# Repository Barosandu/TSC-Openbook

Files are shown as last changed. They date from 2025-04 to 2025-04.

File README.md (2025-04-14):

# Proiect Ariton Alexandru -- TSC -- Openbook

### Pasii de implementare
* Am creat schematicul 2D.
* Am creat PCB-ul, am intampinat niste erori:
    * **Via(hole) error** la componenta USB: am modificat footprint-ul componentei.
    * **Wire to wire error**: am rutat firele manual
* Am atribuit fiecarei componente din library cate un model 3D, si am creat placa 3d (*Push to 3D*)
* Am creat modelele pentru Display si Baterie dupa specificatiile din datasheeturi

### Diagrama block
* salvata in folder cu numele BlockSchematic.png
* Pini ESP32-C6
    * Interfetele SPI -- folosite pentru conectarea la Display
    * Este conectat la senzorul BME688 prin I2C.
    * E conectat la portul USB-C prin interfata USB
    * E conectat la butoane prin porturile GPIO

## Configurație pini ESP32-C6

| Componentă | Pin ESP32-C6 |
|---|---|
| Display SPI | MOSI, CLK, CS, DC |
| BME688 | SDA, SCL (I2C) |
| Butoane | GPIO1, GPIO2, GPIO3 |
| USB-C | D+, D−, VBUS |

Diagrama Bloc

### Componente Folosite

MCU: ESP32-C6-WROOM-1 (sau echivalent), datorita integrarii Wi-Fi 6, BLE 5 si a puterii de procesare ridicate.

Afisaj: Waveshare WSH-13187, e-Paper de 7.5 inch (sau echivalent), cu rezolutie 800x480.

Senzori: Bosch BME688 – pentru temperatura, umiditate, presiune si calitatea aerului.

Baterie: Baterie Li-Polimer de 2500mAh, cu circuit de protectie integrat.

Indicator nivel baterie (Fuel Gauge): Maxim MAX17048 sau echivalent.

Circuit de incarcare: Microchip MCP73831 sau echivalent.

Butoane: Comutatoare tactile Panasonic EVQ-Q2A03W (sau echivalent).

Conector USB-C: Amphenol 12401641E4R (sau echivalent).

Conector pentru card microSD: Attend Tech 112A-TAAR-R03 (sau echivalent).

Ceas in timp real (RTC): DS3231 (sau echivalent), cu supercapacitor pentru backup.

Conector Qwiic/Stemma: pentru conectarea rapida a senzorilor compatibili.

| Componenta | Link |
|---|---|
| adafruit_led | [Link](https://www.snapeda.com/parts/KP-1608SURCK/Kingbright/view-part/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) |
| Button_customv1 | [Link](https://industry.panasonic.com/global/en/products/control/switch/light-touch/number/evqpuj02k) |
| Eagle_ltspice_c | [Link](https://componentsearchengine.com/part-view/0402WGF3001TCE/UNI-ROYAL(Uniroyal%20Elec)) |
| ESP32_WROVER_AVX—SD0805S020S1R0 | [Link](https://ro.mouser.com/ProductDetail/KYOCERA-AVX/SD0805S020S1R0?qs=jCA%252BPfw4LHbpkAoSnwrdjw%3D%3D) |
| ESP32_WROVER_BME680_BME680 | [Link](https://www.snapeda.com/parts/BME680/Bosch/view-part/?welcome=home) |
| ESP32_WROVER_EAGLE-LTSPICE_R | [Link](https://componentsearchengine.com/part-view/R0402%201%25%20100%20K%20(RC0402FR-07100KL)/YAGEO) |
| RCL_CPOL-EU | [Link](https://www.snapeda.com/parts/TAJB475K025RNJ/AVX/view-part/?t=capacitor%203528&con_ref=None) |
| SJ | [Link](https://grabcad.com/library/solder-jumpers-1) |
| R-URI | [Link](https://componentsearchengine.com/part-view/R0402%201%25%20100%20K%20(RC0402FR-07100KL)/YAGEO) |
| ESP32_WROVER_SPARKFUN-DISCRETESEMI_MOSFET_PCH | [Link](https://componentsearchengine.com/part-view/DMG2305UX-7/Diodes%20Incorporated) |
| ESP32_WROVER_SPARKFUN-IC-POWER_MCP73831 | [Link](https://eu.mouser.com/ProductDetail/Microchip-Technology/MCP73831T-2ACI-OT?qs=yUQqVecv4qvbBQBGbHx0Mw%3D%3D) |
| TP | Facut Manual |
| FH34SRJ-24S-0.5SH_99_ | [Link](https://componentsearchengine.com/part-view/FH34SRJ-24S-0.5SH(99)/Hirose) |
| MAX17048G+T10 | [Link](https://www.snapeda.com/parts/MAX17048G+T10/Analog+Devices/view-part/) |
| SAMACSYS_PARTS_USB4110-GF-A | [Link](https://componentsearchengine.com/part-view/USB4110-GF-A/GCT%20(GLOBAL%20CONNECTOR%20TECHNOLOGY)) |
| QWIIC_CONNECTOR | [Link](https://www.snapeda.com/parts/PRT-14417/SparkFun%20Electronics/view-part/?t=QWIIC_CONNECTORJS-1MM) |
| 112A-TAAR-R03_ATTEND | [Link](https://componentsearchengine.com/part-view/112A-TAAR-R03%20ATTEND/ATTEND) |
| 744043680IND_4828-WE-TPC_WRE | [Link](https://componentsearchengine.com/part-view/744043680/W%C3%BCrth%20Elektronik) |
| BD5229G-TR | [Link](https://componentsearchengine.com/part-view/BD5229G-TR/ROHM%20Semiconductor) |
| CPH3225A | [Link](https://componentsearchengine.com/part-view/CPH3225A/Seiko%20Semiconductors) |
| DS3231SN# | [Link](https://componentsearchengine.com/part-view/DS3231SN%23/Analog%20Devices) |
| ESP32-C6-WROOM-1-N8 | [Link](https://componentsearchengine.com/part-view/ESP32-C6-WROOM-1-N8/Espressif%20Systems) |
| MBR0530 | [Link](https://componentsearchengine.com/part-view/MBR0530/onsemi) |
| SI1308EDL-T1-GE3 | [Link](https://componentsearchengine.com/part-view/SI1308EDL-T1-GE3/Vishay) |
| USBLC6-2SC6Y | [Link](https://componentsearchengine.com/part-view/USBLC6-2SC6Y/STMicroelectronics) |
| W25Q512JVEIQ | [Link](https://componentsearchengine.com/part-view/W25Q512JVEIQ/Winbond) |
| XC6220A331MR-G | [Link](https://componentsearchengine.com/part-view/XC6220A331MR-G/Torex) |

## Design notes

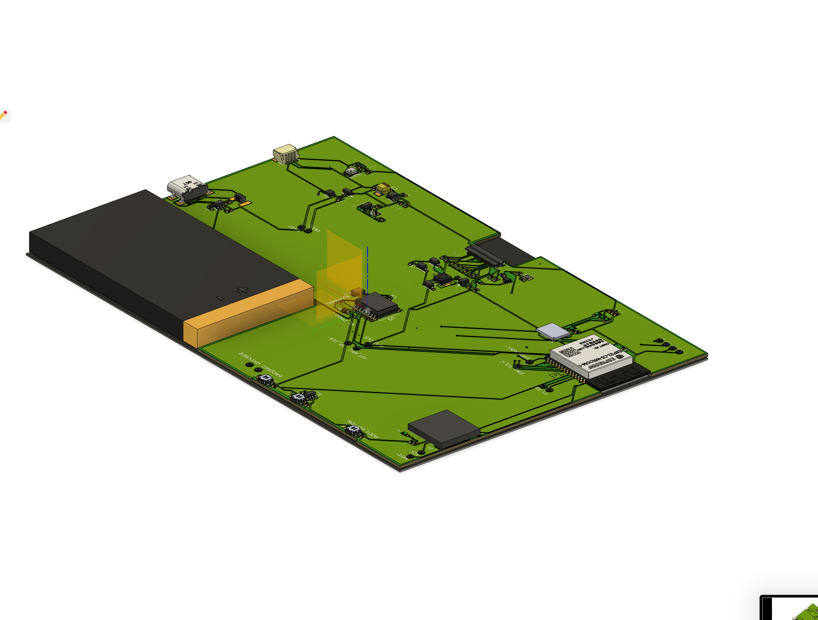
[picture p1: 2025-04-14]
Images/Screenshot 2025-04-14 at 20.04.46.png

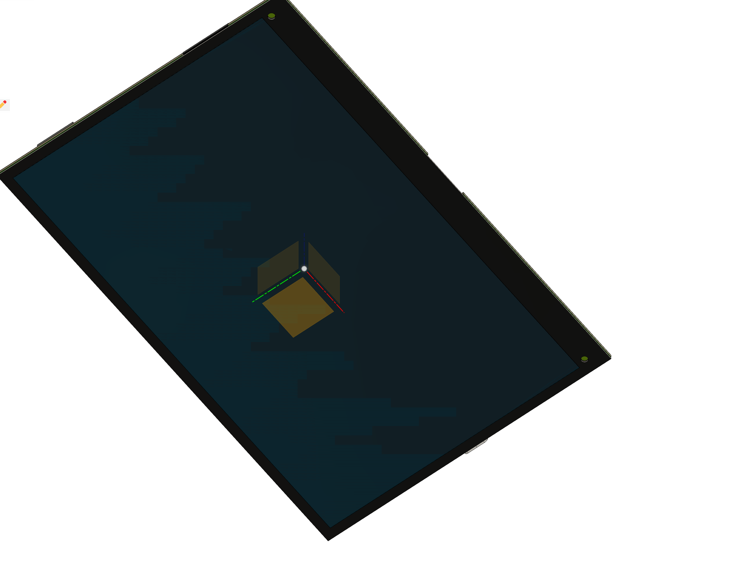
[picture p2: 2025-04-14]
Images/Screenshot 2025-04-14 at 20.04.55.png

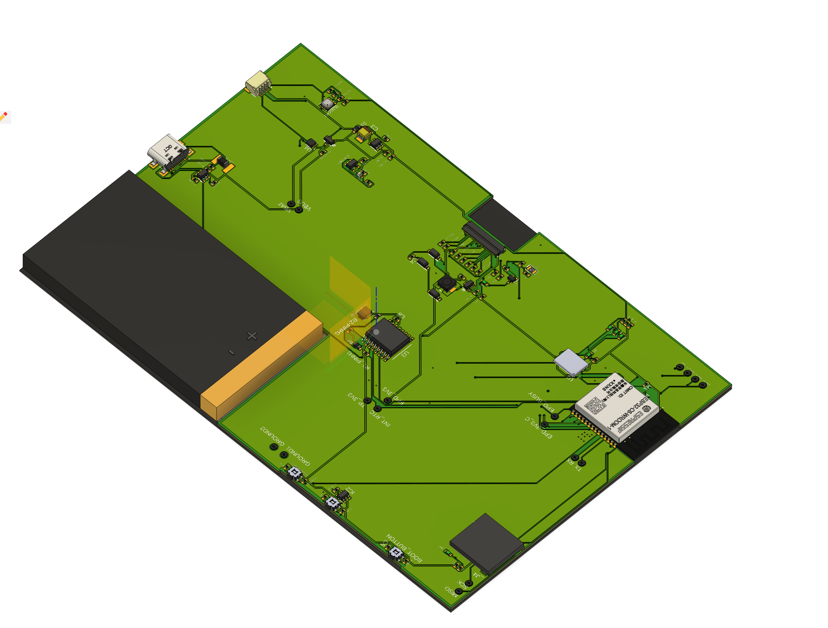
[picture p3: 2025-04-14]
Images/Screenshot 2025-04-14 at 20.04.41.png

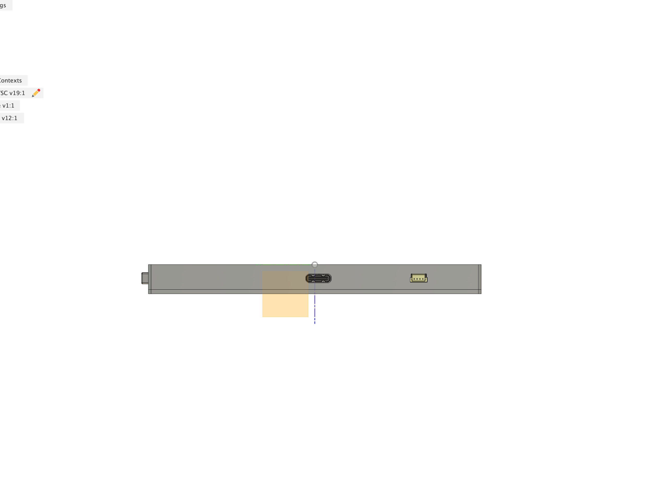
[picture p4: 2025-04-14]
Images/Screenshot 2025-04-14 at 20.05.17.png

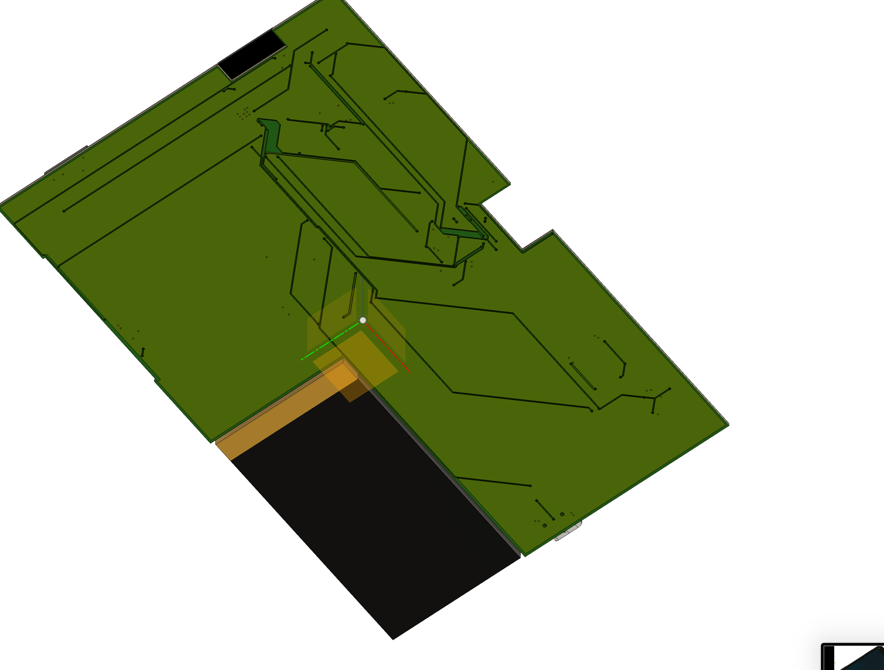
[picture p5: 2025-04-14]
Images/Screenshot 2025-04-14 at 20.05.00.png

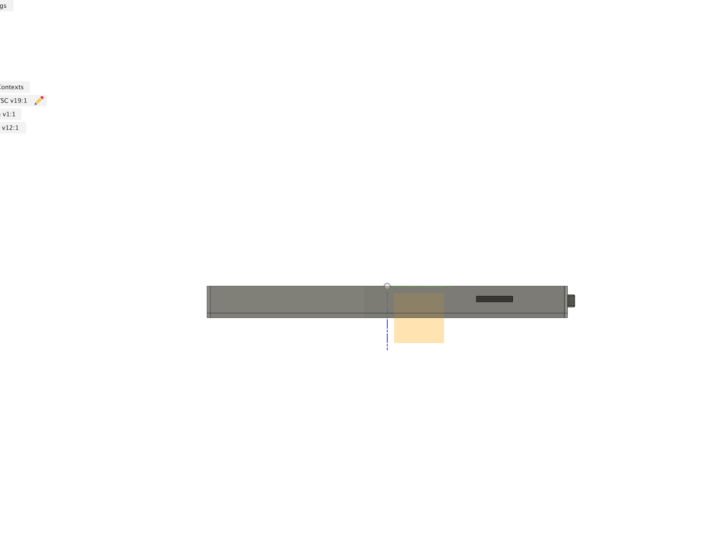
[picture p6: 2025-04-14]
Images/Screenshot 2025-04-14 at 20.05.25.png

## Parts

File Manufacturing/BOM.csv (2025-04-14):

Qty | Value | Device | Package | Parts | Description | ARROW_PART_NUMBER | ARROW_PRICE-STOCK | AVAILABILITY | CENTROID_NOT_SPECIFIED | CHECK_PRICES | COPYRIGHT | DATASHEET | DESCRIPTION | DIGIKEY_DESCRIPTION | DIGIKEY_PART_NUMBER | HEIGHT | LEAD_FREE | MANUFACTURER_NAME | MANUFACTURER_PART_NUMBER | MF | MFR_NAME | MOUSER_PART_NUMBER | MOUSER_PRICE-STOCK | MOUSER_TESTING_PART_NUMBER | MOUSER_TESTING_PRICE-STOCK | MP | MPN | PACKAGE | POPULARITY | PREFIX | PRICE | PROD_ID | PURCHASE-URL | ROHS | SNAPEDA_LINK | SPICEMODEL | SPICEPREFIX | TEMPERATURE_RANGE_HIGH | TEMPERATURE_RANGE_LOW | TP_SIGNAL_NAME | VALUE
1 |  | ADAFRUIT_LEDCHIP-LED0603 | ADAFRUIT_CHIP-LED0603 | CHG_LED | LED
1 |  | SJ | SJ | SJ1 | SMD solder JUMPER |  |  |  |  |  |  |  |  |  |  |  |  |  |  |  |  |  |  |  |  |  |  |  | 3
1 | 0.1uF/50V | EAGLE-LTSPICE_CC0402 | EAGLE-LTSPICE_C0402 | EPD_C5 | CAPACITOR, European symbol |  |  |  |  |  |  |  |  |  |  |  |  |  |  |  |  |  |  |  |  |  |  |  |  |  |  |  |  |  |  | NONE | C
1 | 0.47 | ESP32_WROVER_EAGLE-LTSPICE_RR0402 | ESP32_WROVER_EAGLE-LTSPICE_R0402 | R3 | RESISTOR, European symbol |  |  |  |  |  |  |  |  |  |  |  |  |  |  |  |  |  |  |  |  |  |  |  |  |  |  |  |  |  |  | NONE | R
2 | 100K | ESP32_WROVER_EAGLE-LTSPICE_RR0402 | ESP32_WROVER_EAGLE-LTSPICE_R0402 | R1_BAT, R1_PWRUSB | RESISTOR, European symbol |  |  |  |  |  |  |  |  |  |  |  |  |  |  |  |  |  |  |  |  |  |  |  |  |  |  |  |  |  |  | NONE | R
4 | 100nF | EAGLE-LTSPICE_CC0402 | EAGLE-LTSPICE_C0402 | C1, C2, C4_USB, C8 | CAPACITOR, European symbol |  |  |  |  |  |  |  |  |  |  |  |  |  |  |  |  |  |  |  |  |  |  |  |  |  |  |  |  |  |  | NONE | C
4 | 100nF | ESP32_WROVER_EAGLE-LTSPICE_CC0402 | ESP32_WROVER_EAGLE-LTSPICE_C0402 | C5, C6, C10, C_DELAY | CAPACITOR, European symbol |  |  |  |  |  |  |  |  |  |  |  |  |  |  |  |  |  |  |  |  |  |  |  |  |  |  |  |  |  |  | NONE | C
1 | 100uF | EAGLE-LTSPICE_CC0402 | EAGLE-LTSPICE_C0402 | _C9 | CAPACITOR, European symbol |  |  |  |  |  |  |  |  |  |  |  |  |  |  |  |  |  |  |  |  |  |  |  |  |  |  |  |  |  |  | NONE | C
1 | 100uF TANT | RCL_CPOL-EUCT3528 | RCL_CT3528 | C3 | POLARIZED CAPACITOR, European symbol |  |  |  |  |  |  |  |  |  |  |  |  |  |  |  |  |  |  |  |  |  |  |  | 0 |  |  |  |  |  |  |  | C
16 | 10K | ESP32_WROVER_EAGLE-LTSPICE_RR0402 | ESP32_WROVER_EAGLE-LTSPICE_R0402 | R1, R1-PINH, R1_PINH1, R2-PINH, R2-PINH1, R4, R5, R6, R7, R8, R9, R10, R_BOOT, R_CHANGE, R_CL1, R_RESET | RESISTOR, European symbol |  |  |  |  |  |  |  |  |  |  |  |  |  |  |  |  |  |  |  |  |  |  |  |  |  |  |  |  |  |  | NONE | R
1 | 10uF | EAGLE-LTSPICE_CC0402 | EAGLE-LTSPICE_C0402 | C7 | CAPACITOR, European symbol |  |  |  |  |  |  |  |  |  |  |  |  |  |  |  |  |  |  |  |  |  |  |  |  |  |  |  |  |  |  | NONE | C
1 | 112A-TAAR-R03_ATTEND | 112A-TAAR-R03_ATTEND | 112ATAARR03ATTEND | _J4 | Micro SD Card Socket, Push-Push Type, Top Mount, SMT, H=1.83mm, 10u |  |  |  |  |  |  |  | Micro SD Card Socket | Push-Push Type | Top Mount | SMT | H=1.83mm | 10u |  |  | 1.9mm |  | ATTEND | 112A-TAAR-R03 ATTEND
1 | 15 | ESP32_WROVER_EAGLE-LTSPICE_RR0402 | ESP32_WROVER_EAGLE-LTSPICE_R0402 | R_CAPACITOR | RESISTOR, European symbol |  |  |  |  |  |  |  |  |  |  |  |  |  |  |  |  |  |  |  |  |  |  |  |  |  |  |  |  |  |  | NONE | R
9 | 1uF/50V | EAGLE-LTSPICE_CC0402 | EAGLE-LTSPICE_C0402 | C11, C12, EPD_C1, EPD_C2, EPD_C6, EPD_C7, EPD_C8, EPD_C9, EPD_C10 | CAPACITOR, European symbol |  |  |  |  |  |  |  |  |  |  |  |  |  |  |  |  |  |  |  |  |  |  |  |  |  |  |  |  |  |  | NONE | C
1 | 2.2 | ESP32_WROVER_EAGLE-LTSPICE_RR0402 | ESP32_WROVER_EAGLE-LTSPICE_R0402 | R2 | RESISTOR, European symbol |  |  |  |  |  |  |  |  |  |  |  |  |  |  |  |  |  |  |  |  |  |  |  |  |  |  |  |  |  |  | NONE | R
2 | 20V/4.2A/52mΩ/1.4W | ESP32_WROVER_SPARKFUN-DISCRETESEMI_MOSFET_PCH-DMG2305UX-7 | ESP32_WROVER_SPARKFUN-DISCRETESEMI_SOT23-3 | Q1, Q2 | P-channel MOSFETs |  |  |  |  |  |  |  |  |  |  |  |  |  |  |  |  |  |  |  |  |  |  |  |  |  |  | TRAN-14388 |  |  |  |  |  |  |  |  | 20V/4.2A/52mΩ/1.4W
1 | 2K | ESP32_WROVER_EAGLE-LTSPICE_RR0402 | ESP32_WROVER_EAGLE-LTSPICE_R0402 | R2_BAT | RESISTOR, European symbol |  |  |  |  |  |  |  |  |  |  |  |  |  |  |  |  |  |  |  |  |  |  |  |  |  |  |  |  |  |  | NONE | R
5 | 4.7uF | EAGLE-LTSPICE_CC0402 | EAGLE-LTSPICE_C0402 | C1_BAT, C1_BAT1, C1_BAT2, C2_BAT, C5_USB | CAPACITOR, European symbol |  |  |  |  |  |  |  |  |  |  |  |  |  |  |  |  |  |  |  |  |  |  |  |  |  |  |  |  |  |  | NONE | C
1 | 4.7uF/25v | EAGLE-LTSPICE_CC0402 | EAGLE-LTSPICE_C0402 | C4 | CAPACITOR, European symbol |  |  |  |  |  |  |  |  |  |  |  |  |  |  |  |  |  |  |  |  |  |  |  |  |  |  |  |  |  |  | NONE | C
2 | 5k1 | ESP32_WROVER_EAGLE-LTSPICE_RR0402 | ESP32_WROVER_EAGLE-LTSPICE_R0402 | R2-USB, R2-USB1 | RESISTOR, European symbol |  |  |  |  |  |  |  |  |  |  |  |  |  |  |  |  |  |  |  |  |  |  |  |  |  |  |  |  |  |  | NONE | R
1 | 68uH | 744043680IND_4828-WE-TPC_WRE | IND_4828-WE-TPC_WRE | L1 |  |  |  |  |  |  | Copyright (C) 2024 Ultra Librarian. All rights reserved. |  |  |  |  |  |  |  | 744043680 |  | Wurth Electronics
1 | BD5229G-TR | BD5229G-TR | SOT95P280X125-5N | IC2 | Voltage Detector with Adjustable Delay Time: CMOS processes are utilized to develop high precision, low current consumption CMOS reset ICs that allow arbitrary setting of the delay time. The extensive lineup includes both Nch Open Drain and CMOS output types in a wide range of detection voltages (from 2.3V to 6.0V, in 0.1V steps), enabling selection of the ideal solution based on customer requirements. In addition, the entire series is of course both lead-free and RoHS-compliant. |  |  |  |  |  |  |  | Voltage Detector with Adjustable Delay Time: CMOS processes are utilized to develop high precision | low current consumption CMOS reset ICs that allow arbitrary setting of the delay time. The extensive lineup includes both Nch Open Drain and CMOS output types in a wide range of detection voltages (from 2.3V to 6.0V | in 0.1V steps) | enabling selection of the ideal solution based on customer requirements. In addition | the entire series is of course both lead-free and RoHS-compliant. |  |  | 1.25mm |  | ROHM Semiconductor | BD5229G-TR |  |  | 755-BD5229G-TR | https://www.mouser.co.uk/ProductDetail/ROHM-Semiconductor/BD5229G-TR?qs=4kLU8WoGk0vvnhrrYwdszw%3D%3D
3 | BUTTON_CUSYOMV1 | BUTTON_CUSYOMV1 | MYBUTTON | BOOT_BUTTON, CHANGE_BUTTON, RESET_BUTTON
1 | CPH3225A | CPH3225A | CAPCP3225X100N | C10_SUPERCAP | Cap 0.011F 3.3V 1210 Flat Check availability |  |  | Not in stock |  | https://www.snapeda.com/parts/CPH3225A/Seiko+Instruments/view-part/?ref=eda |  |  | 11 mF (EDLC) Supercapacitor 3.3 V 1210 (3225 Metric) - - |  |  |  |  |  |  | Seiko Instruments |  |  |  |  |  | CPH3225A |  | 1210 Seiko |  |  | None |  | https://www.snapeda.com/api/url_track_click_mouser/?unipart_id=562593&manufacturer=Seiko Instruments&part_name=CPH3225A&search_term=None |  | https://www.snapeda.com/parts/CPH3225A/Seiko+Instruments/view-part/?ref=snap
1 | DS3231SN# | DS3231SN# | SOIC127P1032X265-16N | U3 | Real Time Clock Serial 16-Pin SOIC W T/R Check availability |  |  | In Stock |  | https://www.snapeda.com/parts/DS3231SN%23/Analog+Devices/view-part/?ref=eda |  |  | Extremely Accurate I²C-Integrated RTC/TCXO/Crystal |  |  |  |  |  |  | Analog Devices |  |  |  |  |  | DS3231SN# |  | SOIC-16 Maxim |  |  | None |  | https://www.snapeda.com/api/url_track_click_mouser/?unipart_id=99048&manufacturer=Analog Devices&part_name=DS3231SN#&search_term=None |  | https://www.snapeda.com/parts/DS3231SN%23/Analog+Devices/view-part/?ref=snap
1 | ESP32-C6-WROOM-1-N8 | ESP32-C6-WROOM-1-N8 | XCVR_ESP32-C6-WROOM-1-N8 | U2 | Check availability |  |  | In Stock |  | https://www.snapeda.com/parts/ESP32-C6-WROOM-1-N8/Espressif+Systems/view-part/?ref=eda |  |  | Multiprotocol Modules ESP32-C6 module | Wi-Fi 6 in 2.4 GHz band | Bluetooth 5 | Zigbee 3.0 and Thread. ESP34-WROOM Compatible - ENGINEERING SAMPLE |  |  |  |  |  |  | Espressif Systems |  |  |  |  |  | ESP32-C6-WROOM-1-N8 |  | None |  |  | None |  |  |  | https://www.snapeda.com/parts/ESP32-C6-WROOM-1-N8/Espressif+Systems/view-part/?ref=snap
1 | ESP32C6_VARISTORCN1812 | ESP32C6_VARISTORCN1812 | ESP32C6_VARISTOR_CT/CN1812 | PFMF.050.1 | VARISTOR |  |  |  |  |  |  |  |  |  |  |  |  |  |  |  |  |  |  |  |  |  |  |  | 0
2 | ESP32_WROVER_AVX---SD0805S020S1R0_AVX_SD0805S020S1R0_0_0AVX_SD0805S020S1R0_0_0 | ESP32_WROVER_AVX---SD0805S020S1R0_AVX_SD0805S020S1R0_0_0AVX_SD0805S020S1R0_0_0 | ESP32_WROVER_AVX---SD0805S020S1R0_AVX_SD0805S020S1R0_0 | D2, D7 | Schottky Barrier Rectifier Diode |  |  |  | No |  |  | http://datasheets.avx.com/schottky.pdf |  | DIODE SCHOTTKY 20V 1A 0805 | 478-7800-1-ND |  | yes |  |  | AVX |  | 581-SD0805S020S1R0 |  |  |  |  |  | 0805 (2012 metric) |  | D |  |  |  | yes |  |  |  | +125°C | -55°C
1 | ESP32_WROVER_BME680_BME680 | ESP32_WROVER_BME680_BME680 | ESP32_WROVER_BME680_PSON80P300X300X100-8N | SENSOR2 | Integrated Environmental Unit |  |  | Unavailable |  |  |  |  | Integrated Environmental Unit |  |  |  |  |  |  | Bosch Sensortec |  |  |  |  |  | BME680 |  | LGA-8 Bosch Tools |  |  | None
1 | ESP32_WROVER_SPARKFUN-IC-POWER_MCP73831 | ESP32_WROVER_SPARKFUN-IC-POWER_MCP73831 | ESP32_WROVER_SPARKFUN-IC-POWER_SOT23-5 | MCP73831 | MCP73831T Li-Ion, Li-Pol Controller |  |  |  |  |  |  |  |  |  |  |  |  |  |  |  |  |  |  |  |  |  |  |  |  |  |  | IC-09995
1 | FH34SRJ-24S-0.5SH_99_ | FH34SRJ-24S-0.5SH_99_ | FH34SRJ24S05SH99 | J1 | (0.50mm) Surface Mount, Right Angle |  |  |  |  |  |  |  | 24 Position FFC | FPC Connector Contacts | (0.50mm) Surface Mount | Right Angle |  |  | 1.1mm |  | Hirose | FH34SRJ-24S-0.5SH(99) |  |  | 798-FH34SRJ24S05SH99 | https://www.mouser.co.uk/ProductDetail/Hirose-Connector/FH34SRJ-24S-0.5SH99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
1 | MAX17048G+T10 | MAX17048G+T10 | SON50P200X200X80-9N | U4 | Check availability |  |  | In Stock |  | https://www.snapeda.com/parts/MAX17048G+T10/Analog+Devices/view-part/?ref=eda |  |  | 3µA 1-Cell/2-Cell Fuel Gauge with ModelGauge |  |  |  |  |  |  | Analog Devices |  |  |  |  |  | MAX17048G+T10 |  | TDFN-8 Maxim |  |  | None |  | https://www.snapeda.com/api/url_track_click_mouser/?unipart_id=329239&manufacturer=Analog Devices&part_name=MAX17048G+T10&search_term=None |  | https://www.snapeda.com/parts/MAX17048G+T10/Analog+Devices/view-part/?ref=snap
3 | MBR0530 | MBR0530 | SOD3716X135N | D3, D4, D5 | ON SEMICONDUCTOR - MBR0530 - DIODE, SCHOTTKY, 0.5A, 30V, SOD-123 |  |  | In Stock |  | https://www.snapeda.com/parts/MBR0530/Onsemi/view-part/?ref=eda |  |  | Diode Schottky 30 V 500mA Surface Mount SOD-123 |  |  |  |  |  |  | ON Semiconductor |  |  |  |  |  | MBR0530 |  | SOD-123-2 ON Semiconductor |  |  | None |  | https://www.snapeda.com/api/url_track_click_mouser/?unipart_id=179458&manufacturer=ON Semiconductor&part_name=MBR0530&search_term=None |  | https://www.snapeda.com/parts/MBR0530/Onsemi/view-part/?ref=snap
6 | PGB1010603MR | PGB1010603MR | DIOC1608X36N | _D6, _D8, _D9, _D10, _D11, _D12 | Check availability |  |  | In Stock |  | https://www.snapeda.com/parts/PGB1010603MR/Littelfuse/view-part/?ref=eda |  |  | 150V (Typ) Clamp - Ipp Tvs Diode Surface Mount 0603 (1608 Metric) |  |  |  |  |  |  | Littelfuse Inc. |  |  |  |  |  | PGB1010603MR |  | 0603 Littelfuse Inc. |  |  | None |  | https://www.snapeda.com/api/url_track_click_mouser/?unipart_id=5659453&manufacturer=Littelfuse Inc.&part_name=PGB1010603MR&search_term=None |  | https://www.snapeda.com/parts/PGB1010603MR/Littelfuse/view-part/?ref=snap
1 | QWIIC_RIGHT_ANGLE | QWIIC_CONNECTORJS-1MM | JST04_1MM_RA | J4 | SparkFun I2C Standard Qwiic Connector |  |  |  |  |  |  |  |  |  |  |  |  |  |  |  |  |  |  |  |  |  |  |  |  |  |  | CONN-13694 |  |  |  |  |  |  |  |  | QWIIC_RIGHT_ANGLE
1 | SAMACSYS_PARTS_USB4110-GF-A | SAMACSYS_PARTS_USB4110-GF-A | SAMACSYS_PARTS_USB4110GFA | _J2 | CONN USB 2.0 TYPE-C R/A SMT |  |  |  |  |  |  |  | CONN USB 2.0 TYPE-C R/A SMT |  |  | 3.26mm |  | GCT (GLOBAL CONNECTOR TECHNOLOGY) | USB4110-GF-A |  |  | 640-USB4110-GF-A | https://www.mouser.co.uk/ProductDetail/GCT/USB4110-GF-A?qs=KUoIvG%2F9IlYiZvIXQjyJeA%3D%3D
1 | SI1308EDL-T1-GE3 | SI1308EDL-T1-GE3 | SOT65P210X110-3N | _Q3 | MOSFET N-Ch 30V 1.5A TrenchFET SC70 Vishay Si1308EDL-T1-GE3 N-channel MOSFET Transistor, 1.5 A, 30 V, 3-Pin SC-70 |  |  | In Stock |  | https://www.snapeda.com/parts/SI1308EDL-T1-GE3/Vishay+Siliconix/view-part/?ref=eda |  |  | Si1308EDL-T1-GE3 N-channel MOSFET Transistor | 1.5 A | 30 V | 3-Pin SC-70 | Siliconix / Vishay SI1308EDL-T1-GE3 |  |  |  |  |  |  | Vishay Siliconix |  |  |  |  |  | SI1308EDL-T1-GE3 |  | SOT-323 Vishay Semiconductor |  |  | None |  | https://www.snapeda.com/api/url_track_click_mouser/?unipart_id=274603&manufacturer=Vishay Siliconix&part_name=SI1308EDL-T1-GE3&search_term=None |  | https://www.snapeda.com/parts/SI1308EDL-T1-GE3/Vishay+Siliconix/view-part/?ref=snap
17 | TPTP20R | TPTP20R | TP20R | EPD_3V3, EPD_3V3_C, EPD_BUSY, EPD_CS, EPD_DC, EPD_RST, GROUND1, GROUND2, INT_RTC, MISO, MOSI, RX, SCK, TP_3V3, TX, VBAT, VBUS | Test pad |  |  |  |  |  |  |  |  |  |  |  |  |  |  |  |  |  |  |  |  |  |  |  | 2
1 | USBLC6-2SC6Y | USBLC6-2SC6Y | SOT95P280X145-6N | D1 | Low Cap. ESD Protection Auto SOT-23-6 STMicroelectronics USBLC6-2SC6Y, Dual Uni-Directional TVS Diode Array, 6-Pin SOT-23 |  |  | In Stock |  | https://www.snapeda.com/parts/USBLC6-2SC6Y/STMicroelectronics/view-part/?ref=eda |  |  | 17V Clamp 5A (8/20µs) Ipp Tvs Diode Surface Mount SOT-23-6 |  |  |  |  |  |  | STMicroelectronics |  |  |  |  |  | USBLC6-2SC6Y |  | SOT-23-6 STMicroelectronics |  |  | None |  |  |  | https://www.snapeda.com/parts/USBLC6-2SC6Y/STMicroelectronics/view-part/?ref=snap
1 | W25Q512JVEIQ | W25Q512JVEIQ | SON127P600X800X80-9N | U1 | Check availability |  |  | In Stock |  | https://www.snapeda.com/parts/W25Q512JVEIQ/Winbond+Electronics/view-part/?ref=eda |  |  | FLASH - NOR Memory IC 512Mb (64M x 8) SPI - Quad I/O 133 MHz 8-WSON (8x6) |  |  |  |  |  |  | Winbond Electronics |  |  |  |  |  | W25Q512JVEIQ |  | Package |  |  | None |  |  |  | https://www.snapeda.com/parts/W25Q512JVEIQ/Winbond+Electronics/view-part/?ref=snap
1 | XC6220A331MR-G | XC6220A331MR-G | SOT95P280X120-5N | IC4 | LDO Voltage Regulators |  |  |  |  |  |  |  | LDO Voltage Regulators |  |  | 1.2mm |  | Torex | XC6220A331MR-G |  |  | 865-XC6220A331MR-G | https://www.mouser.co.uk/ProductDetail/Torex-Semiconductor/XC6220A331MR-G?qs=AsjdqWjXhJ8ZSWznL1J0gg%3D%3D

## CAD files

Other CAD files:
Mechanical/openbook_3d_file_ariton_alexandru.f3z

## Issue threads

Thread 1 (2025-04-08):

[Enhancement] Imbunatatire labels

Sorin-Popescu135, 2025-04-08:
Apropie label-urile mai mult de fire, si poate schimba fontul pentru claritate

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

dantudose, 2025-04-09:
Textul de la labels e prea mare, se rezolva daca faci resize la ele. Cred ca sunt 0.7 acum si daca le reduci la 0.5 se alinieaza perfect.

Closed 2025-04-14.

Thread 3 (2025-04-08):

[Enhancement] [Bug] Via Stitching

Sorin-Popescu135, 2025-04-08:
Micsoreaza spatiile negre din PCB

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

Barosandu, 2025-04-14:
Fixed in #4

Closed 2025-04-14.

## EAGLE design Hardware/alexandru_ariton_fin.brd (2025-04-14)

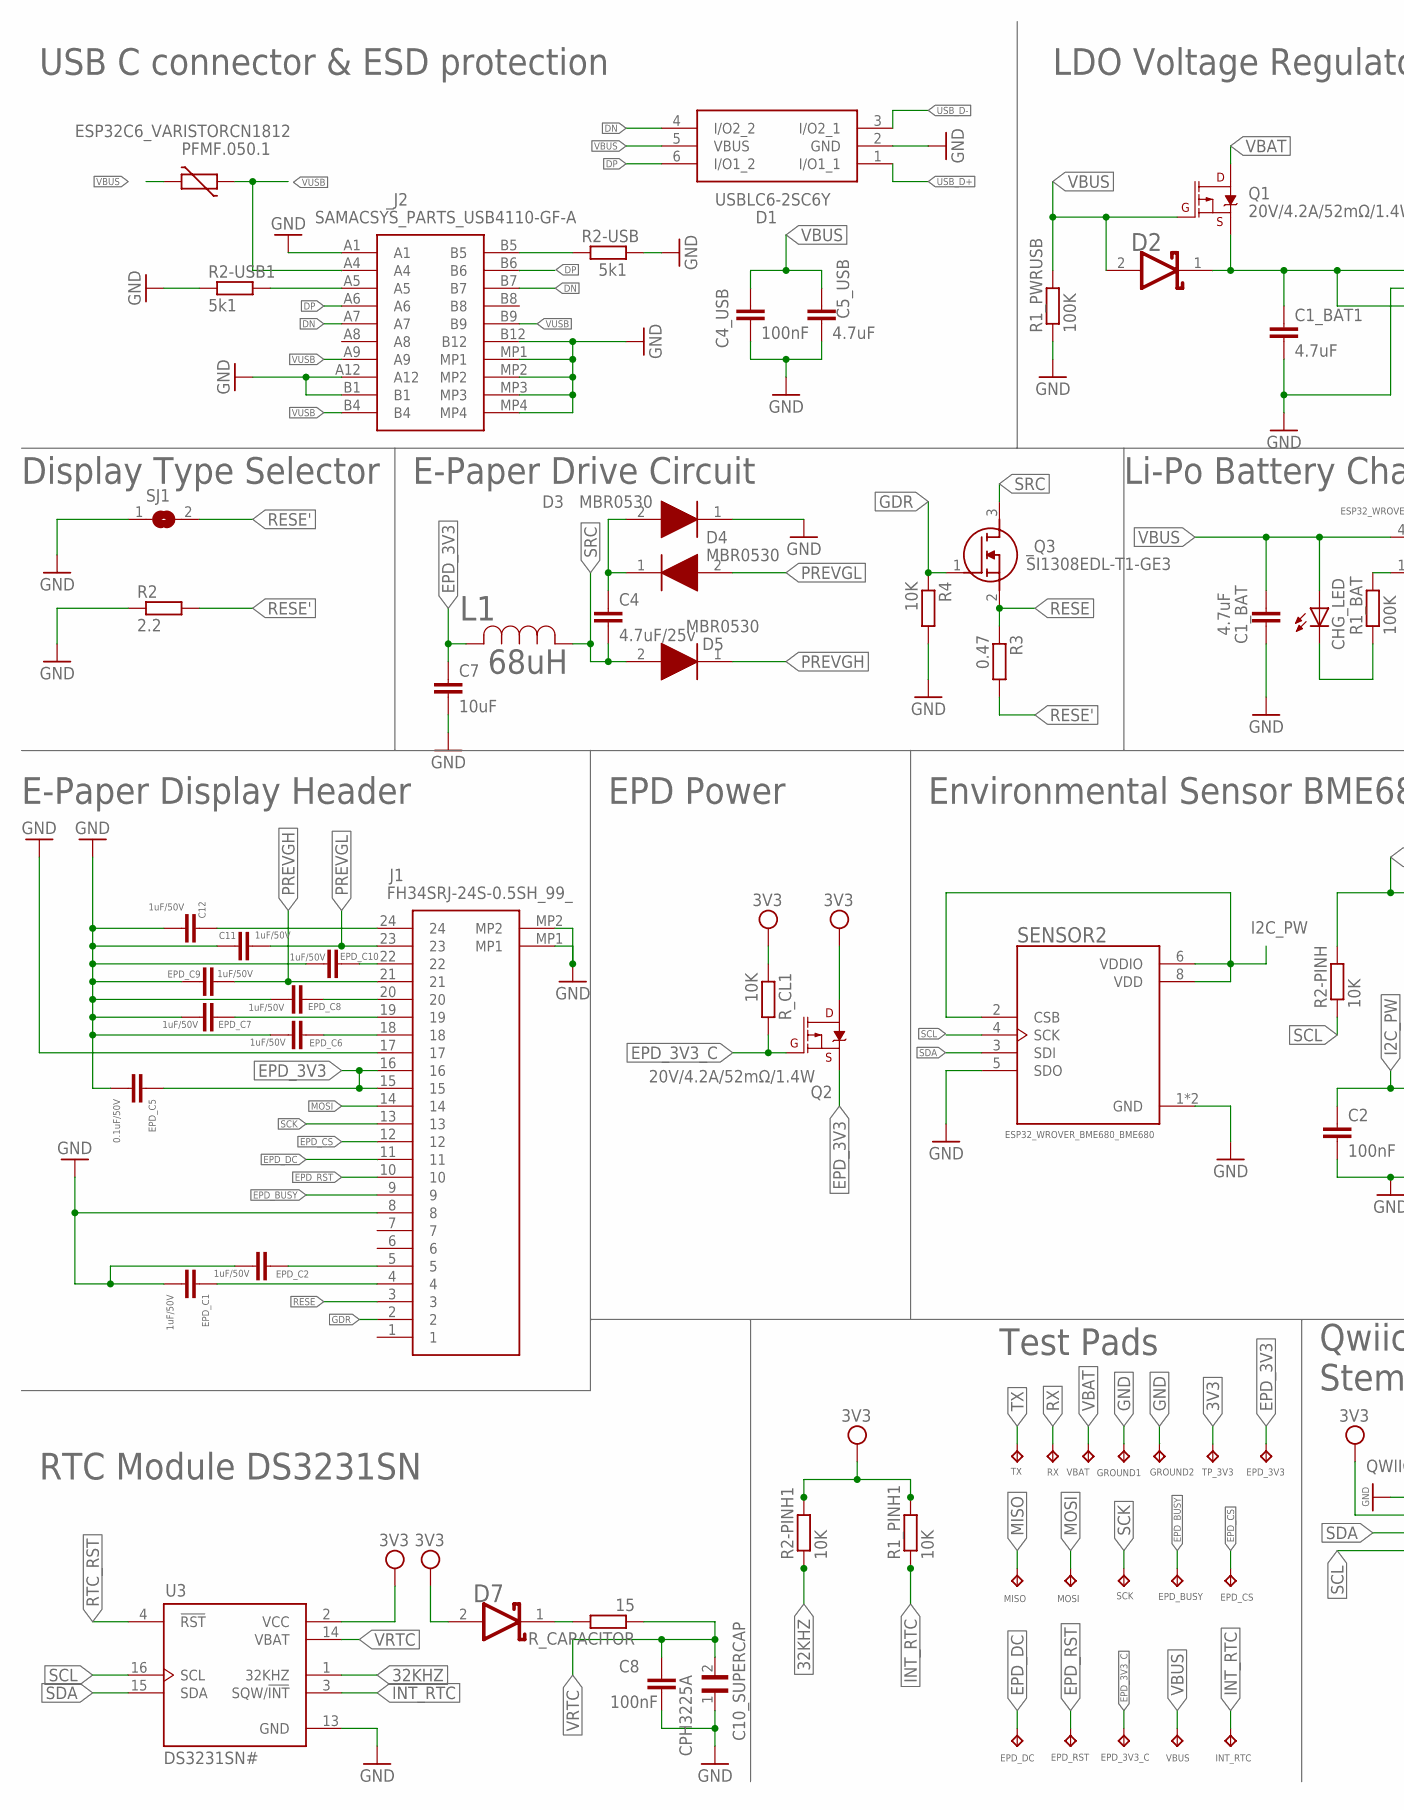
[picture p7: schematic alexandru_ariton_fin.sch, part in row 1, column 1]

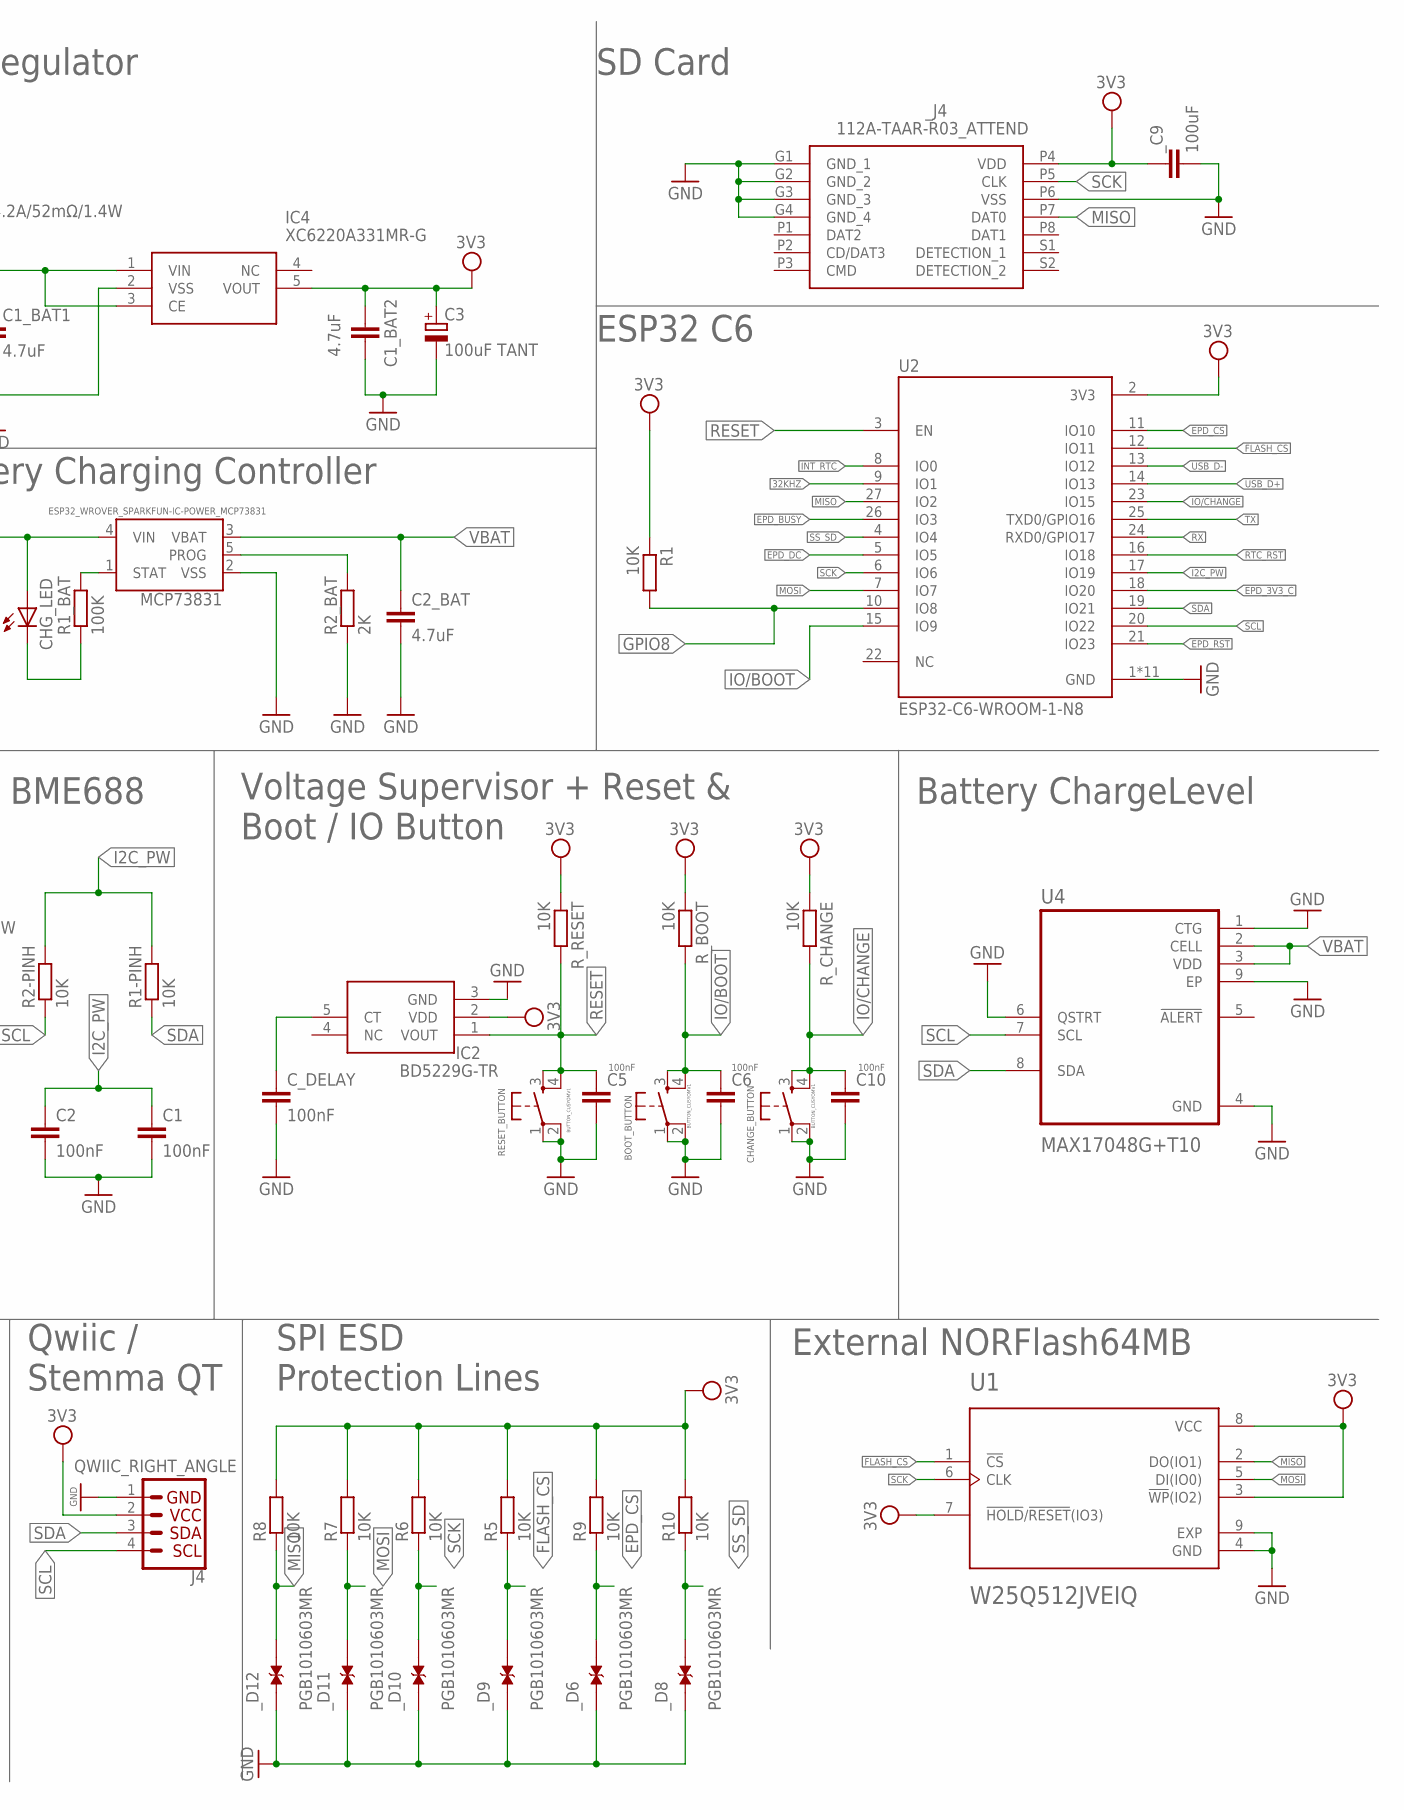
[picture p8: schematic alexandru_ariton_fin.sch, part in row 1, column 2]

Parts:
BOOT_BUTTON: BUTTON_CUSYOMV1; MYBUTTON
C1, C2, C4_USB, C8: 100nF; EAGLE-LTSPICE_C0402
C1_BAT, C1_BAT1, C1_BAT2, C2_BAT, C5_USB: 4.7uF; EAGLE-LTSPICE_C0402
C3: 100uF TANT; RCL_CT3528
C4: 4.7uF/25v; EAGLE-LTSPICE_C0402
C5, C6, C10: 100nF; ESP32_WROVER_EAGLE-LTSPICE_C0402
C7: 10uF; EAGLE-LTSPICE_C0402
C10_SUPERCAP: CPH3225A; CAPCP3225X100N
C11, C12: 1uF/50V; EAGLE-LTSPICE_C0402
CHANGE_BUTTON: BUTTON_CUSYOMV1; MYBUTTON
CHG_LED: ADAFRUIT_LEDCHIP-LED0603; ADAFRUIT_CHIP-LED0603
C_DELAY: 100nF; ESP32_WROVER_EAGLE-LTSPICE_C0402
D1: USBLC6-2SC6Y; SOT95P280X145-6N
D2, D7: ESP32_WROVER_AVX---SD0805S020S1R0_AVX_SD0805S020S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; ESP32_WROVER_AVX---SD0805S020S1R0_AVX_SD0805S020S1R0_0
D3, D4, D5: MBR0530; SOD3716X135N
EPD_3V3, EPD_3V3_C: TPTP20R; TP20R
EPD_BUSY: TPTP20R; TP20R
EPD_C1, EPD_C2, EPD_C6, EPD_C7, EPD_C8, EPD_C9, EPD_C10: 1uF/50V; EAGLE-LTSPICE_C0402
EPD_C5: 0.1uF/50V; EAGLE-LTSPICE_C0402
EPD_CS: TPTP20R; TP20R
EPD_DC: TPTP20R; TP20R
EPD_RST: TPTP20R; TP20R
GROUND1, GROUND2: TPTP20R; TP20R
IC2: BD5229G-TR; SOT95P280X125-5N
IC4: XC6220A331MR-G; SOT95P280X120-5N
INT_RTC: TPTP20R; TP20R
J1: FH34SRJ-24S-0.5SH_99_; FH34SRJ24S05SH99
J4: QWIIC_RIGHT_ANGLE; JST04_1MM_RA
L1: 68uH; IND_4828-WE-TPC_WRE
MCP73831: ESP32_WROVER_SPARKFUN-IC-POWER_MCP73831; ESP32_WROVER_SPARKFUN-IC-POWER_SOT23-5
MISO: TPTP20R; TP20R
MOSI: TPTP20R; TP20R
PFMF.050.1: ESP32C6_VARISTORCN1812; ESP32C6_VARISTOR_CT/CN1812
Q1, Q2: 20V/4.2A/52mΩ/1.4W; ESP32_WROVER_SPARKFUN-DISCRETESEMI_SOT23-3
R1, R1-PINH, R1_PINH1, R2-PINH, R2-PINH1, R4, R5, R6, R7, R8, R9, R10: 10K; ESP32_WROVER_EAGLE-LTSPICE_R0402
R1_BAT, R1_PWRUSB: 100K; ESP32_WROVER_EAGLE-LTSPICE_R0402
R2: 2.2; ESP32_WROVER_EAGLE-LTSPICE_R0402
R2-USB, R2-USB1: 5k1; ESP32_WROVER_EAGLE-LTSPICE_R0402
R2_BAT: 2K; ESP32_WROVER_EAGLE-LTSPICE_R0402
R3: 0.47; ESP32_WROVER_EAGLE-LTSPICE_R0402
RESET_BUTTON: BUTTON_CUSYOMV1; MYBUTTON
RX: TPTP20R; TP20R
R_BOOT: 10K; ESP32_WROVER_EAGLE-LTSPICE_R0402
R_CAPACITOR: 15; ESP32_WROVER_EAGLE-LTSPICE_R0402
R_CHANGE: 10K; ESP32_WROVER_EAGLE-LTSPICE_R0402
R_CL1: 10K; ESP32_WROVER_EAGLE-LTSPICE_R0402
R_RESET: 10K; ESP32_WROVER_EAGLE-LTSPICE_R0402
SCK: TPTP20R; TP20R
SENSOR2: ESP32_WROVER_BME680_BME680; ESP32_WROVER_BME680_PSON80P300X300X100-8N
SJ1: SJ
TP_3V3: TPTP20R; TP20R
TX: TPTP20R; TP20R
U1: W25Q512JVEIQ; SON127P600X800X80-9N
U2: ESP32-C6-WROOM-1-N8; XCVR_ESP32-C6-WROOM-1-N8
U3: DS3231SN#; SOIC127P1032X265-16N
U4: MAX17048G+T10; SON50P200X200X80-9N
VBAT: TPTP20R; TP20R
VBUS: TPTP20R; TP20R
_C9: 100uF; EAGLE-LTSPICE_C0402
_D6, _D8, _D9, _D10, _D11, _D12: PGB1010603MR; DIOC1608X36N
_J2: SAMACSYS_PARTS_USB4110-GF-A; SAMACSYS_PARTS_USB4110GFA
_J4: 112A-TAAR-R03_ATTEND; 112ATAARR03ATTEND
_Q3: SI1308EDL-T1-GE3; SOT65P210X110-3N

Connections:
3V3: C1_BAT2.1, C3.+, D7.2 (ANODE), IC2.2 (VDD), IC4.5 (VOUT), J4.2, Q2.3 (D), R1.1, R1_PINH1.2, R2-PINH1.2, R5.2, R6.2, R7.2, R8.2, R9.2, R10.2, R_BOOT.1, R_CHANGE.1, R_CL1.1, R_RESET.1, TP_3V3.TP, U1.3 (!WP!(IO2)), U1.7 (!HOLD!/!RESET!(IO3)), U1.8 (VCC), U2.2 (3V3), U3.2 (VCC), _C9.1, _J4.P4 (VDD)
32KHZ: R2-PINH1.1, U2.9 (IO1), U3.1 (32KHZ)
DN: D1.4 (I/O2_2), _J2.A7, _J2.B7
DP: D1.6 (I/O1_2), _J2.A6, _J2.B6
EPD_3V3: C7.1, EPD_3V3.TP, EPD_C5.1, J1.15, J1.16, L1.2, Q2.2 (S)
EPD_3V3_C: EPD_3V3_C.TP, Q2.1 (G), R_CL1.2, U2.18 (IO20)
EPD_BUSY: EPD_BUSY.TP, J1.9, U2.26 (IO3)
EPD_CS: EPD_CS.TP, J1.12, R9.1, U2.11 (IO10), _D6.2
EPD_DC: EPD_DC.TP, J1.11, U2.5 (IO5)
EPD_RST: EPD_RST.TP, J1.10, U2.21 (IO23)
FLASH_CS: R5.1, U1.1 (!CS), U2.12 (IO11), _D9.2
GDR: J1.2, R4.1, _Q3.1 (G)
GND: BOOT_BUTTON.1, BOOT_BUTTON.2, C1.2, C1_BAT.2, C1_BAT1.2, C1_BAT2.2, C2.2, C2_BAT.2, C3.-, C4_USB.2, C5.2, C5_USB.2, C6.2, C7.2, C8.2, C10.2, C10_SUPERCAP.1, C11.2, C12.2, CHANGE_BUTTON.1, CHANGE_BUTTON.2, C_DELAY.2, D1.2 (GND), D3.1 (K), EPD_C1.2, EPD_C2.2, EPD_C5.2, EPD_C6.2, EPD_C7.2, EPD_C8.2, EPD_C9.2, EPD_C10.2, GROUND1.TP, GROUND2.TP, IC2.3 (GND), IC4.2 (VSS), J1.8, J1.17, J1.MP1, J1.MP2, J4.1, MCP73831.2 (VSS), R1_PWRUSB.1, R2.1, R2-USB.2, R2-USB1.1, R2_BAT.1, R4.2, RESET_BUTTON.1, RESET_BUTTON.2, SENSOR2.1 (GND), SENSOR2.5 (SDO), SENSOR2.7 (GND), SJ1.1, U1.4 (GND), U1.9 (EXP), U2.1 (GND), U2.28 (GND), U2.29_1 (GND), U2.29_2 (GND), U2.29_3 (GND), U2.29_4 (GND), U2.29_5 (GND), U2.29_6 (GND), U2.29_7 (GND), U2.29_8 (GND), U2.29_9 (GND), U3.13 (GND), U4.1 (CTG), U4.4 (GND), U4.6 (QSTRT), U4.9 (EP), _C9.2, _D6.1, _D8.1, _D9.1, _D10.1, _D11.1, _D12.1, _J2.A1, _J2.A12, _J2.B1, _J2.B12, _J2.MP1, _J2.MP2, _J2.MP3, _J2.MP4, _J4.G1 (GND_1), _J4.G2 (GND_2), _J4.G3 (GND_3), _J4.G4 (GND_4), _J4.P6 (VSS)
GPIO8: R1.2, U2.10 (IO8)
I2C_PW: C1.1, C2.1, R1-PINH.2, R2-PINH.2, SENSOR2.2 (CSB), SENSOR2.6 (VDDIO), SENSOR2.8 (VDD), U2.17 (IO19)
INT_RTC: INT_RTC.TP, R1_PINH1.1, U2.8 (IO0), U3.3 (SQW/!INT)
IO/BOOT: BOOT_BUTTON.3, BOOT_BUTTON.4, C6.1, R_BOOT.2, U2.15 (IO9)
IO/CHANGE: C10.1, CHANGE_BUTTON.3, CHANGE_BUTTON.4, R_CHANGE.2, U2.23 (IO15)
MISO: MISO.TP, R8.1, U1.2 (DO(IO1)), U2.27 (IO2), _D12.2, _J4.P7 (DAT0)
MOSI: J1.14, MOSI.TP, R7.1, U1.5 (DI(IO0)), U2.7 (IO7), _D11.2
unnamed: R2-USB.1, _J2.B5
unnamed: R2-USB1.2, _J2.A5
unnamed: C1_BAT1.1, D2.1 (CATHODE), IC4.1 (VIN), IC4.3 (CE), Q1.2 (S)
unnamed: MCP73831.1 (STAT), R1_BAT.2
unnamed: C4.1, D3.2 (A), D4.1 (K)
unnamed: CHG_LED.C, R1_BAT.1
unnamed: MCP73831.5 (PROG), R2_BAT.2
unnamed: C12.1, J1.24
unnamed: EPD_C10.1, J1.22
unnamed: EPD_C8.1, J1.20
unnamed: EPD_C7.1, J1.19
unnamed: EPD_C6.1, J1.18
unnamed: D7.1 (CATHODE), R_CAPACITOR.2
unnamed: C_DELAY.1, IC2.5 (CT)
unnamed: EPD_C1.1, J1.4
unnamed: EPD_C2.1, J1.5
PREVGH: D5.1 (K), EPD_C9.1, J1.21
PREVGL: C11.1, D4.2 (A), J1.23
RESE: J1.3, R3.1, _Q3.2 (S)
RESE': R2.2, R3.2, SJ1.2
RESET: C5.1, IC2.1 (VOUT), RESET_BUTTON.3, RESET_BUTTON.4, R_RESET.2, U2.3 (EN)
RTC_RST: U2.16 (IO18), U3.4 (!RST)
RX: RX.TP, U2.24 (RXD0/GPIO17)
SCK: J1.13, R6.1, SCK.TP, U1.6 (CLK), U2.6 (IO6), _D10.2, _J4.P5 (CLK)
SCL: J4.4, R2-PINH.1, SENSOR2.4 (SCK), U2.20 (IO22), U3.16 (SCL), U4.7 (SCL)
SDA: J4.3, R1-PINH.1, SENSOR2.3 (SDI), U2.19 (IO21), U3.15 (SDA), U4.8 (SDA)
SRC: C4.2, D5.2 (A), L1.1, _Q3.3 (D)
SS_SD: R10.1, U2.4 (IO4), _D8.2
TX: TX.TP, U2.25 (TXD0/GPIO16)
USB_D+: D1.1 (I/O1_1), U2.14 (IO13)
USB_D-: D1.3 (I/O2_1), U2.13 (IO12)
VBAT: C2_BAT.1, MCP73831.3 (VBAT), Q1.3 (D), U4.2 (CELL), U4.3 (VDD), VBAT.TP
VBUS: C1_BAT.1, C4_USB.1, C5_USB.1, CHG_LED.A, D1.5 (VBUS), D2.2 (ANODE), MCP73831.4 (VIN), PFMF.050.1.2, Q1.1 (G), R1_PWRUSB.2, VBUS.TP
VRTC: C8.1, C10_SUPERCAP.2, R_CAPACITOR.1, U3.14 (VBAT)
VUSB: PFMF.050.1.1, _J2.A4, _J2.A9, _J2.B4, _J2.B9

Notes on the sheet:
USB C connector & ESD protection
LDO Voltage Regulator
SD Card
Display Type Selector
E-Paper Drive Circuit
Li-Po Battery Charging Controller
ESP32 C6
E-Paper Display Header
EPD Power
Environmental Sensor BME688
Voltage Supervisor + Reset & Boot / IO Button
Battery ChargeLevel
RTC Module DS3231SN
Test Pads
Qwiic / Stemma QT
SPI ESD Protection Lines
External NORFlash64MB

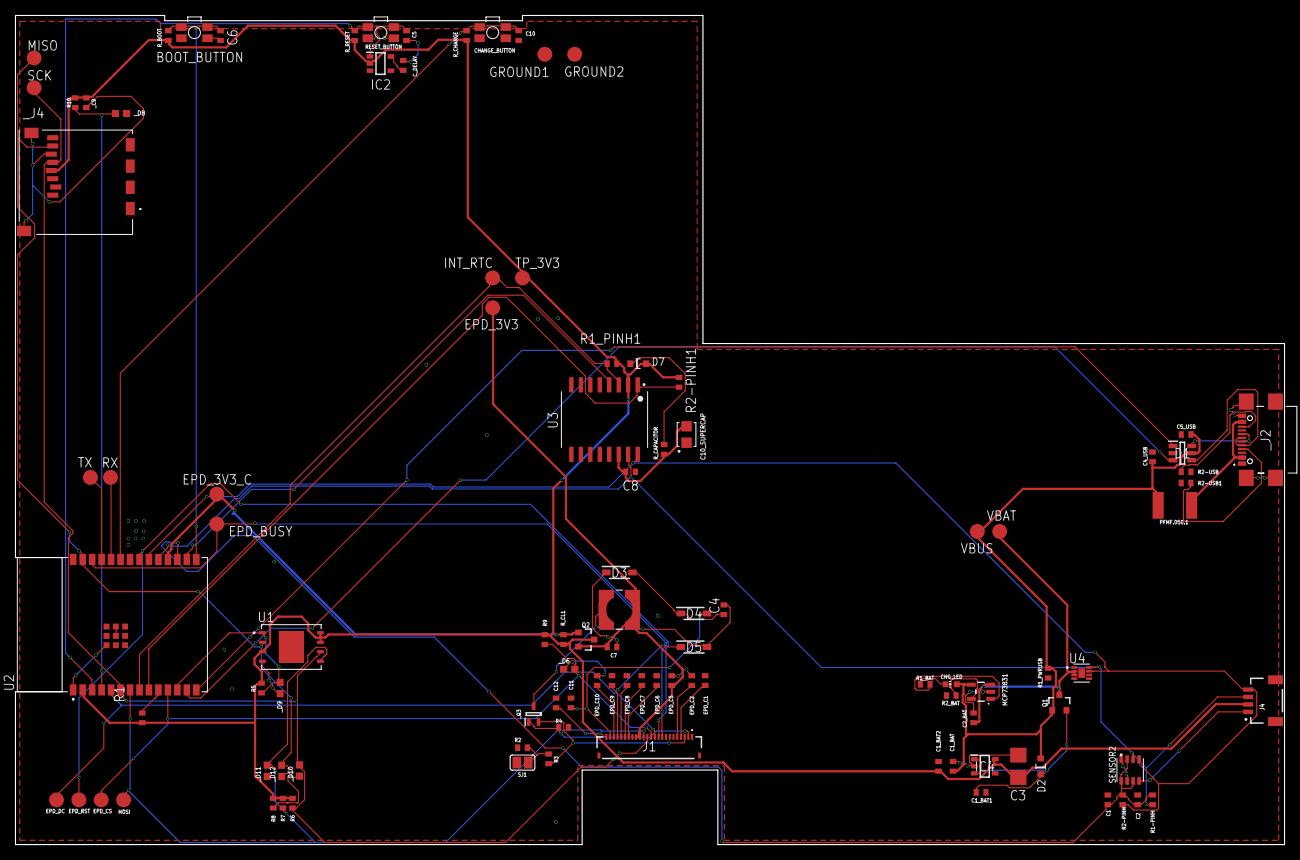
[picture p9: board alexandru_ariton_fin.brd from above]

Board: 2 copper layers, 170.2 x 111.2 mm, 103 parts (0 on the bottom side), 55 nets.

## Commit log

2025-04-05 Totul inafara de readme
    [BOM.csv, Pick_and_place.csv, alexandru_ariton.brd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]
2025-04-14 Fixed: via stitching, big labels, no holes in base screen
    [BOM.csv, OpenBook Enclosure v25.f3z, Pick_and_place.csv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]
2025-04-14 Renamed a file
    [alexandru_ariton_fin.sch]

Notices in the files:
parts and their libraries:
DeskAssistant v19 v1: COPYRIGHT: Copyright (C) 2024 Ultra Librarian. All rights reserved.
